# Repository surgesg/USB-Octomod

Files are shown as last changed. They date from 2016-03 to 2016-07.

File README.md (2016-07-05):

# USB-Octomod

The USB-Octomod is a USB device which allows generation of computer-controlled analog synthesizer control voltages
in the range of approximately +/- 5V.
Using a small open-source and cross-platform host application, the user is able to control the 8 output channels
of the Octomod through a simple OSC/MIDI interface. 
The OSC interface allows composers, musicians, etc. to control the Octomod from their software environment of choice.

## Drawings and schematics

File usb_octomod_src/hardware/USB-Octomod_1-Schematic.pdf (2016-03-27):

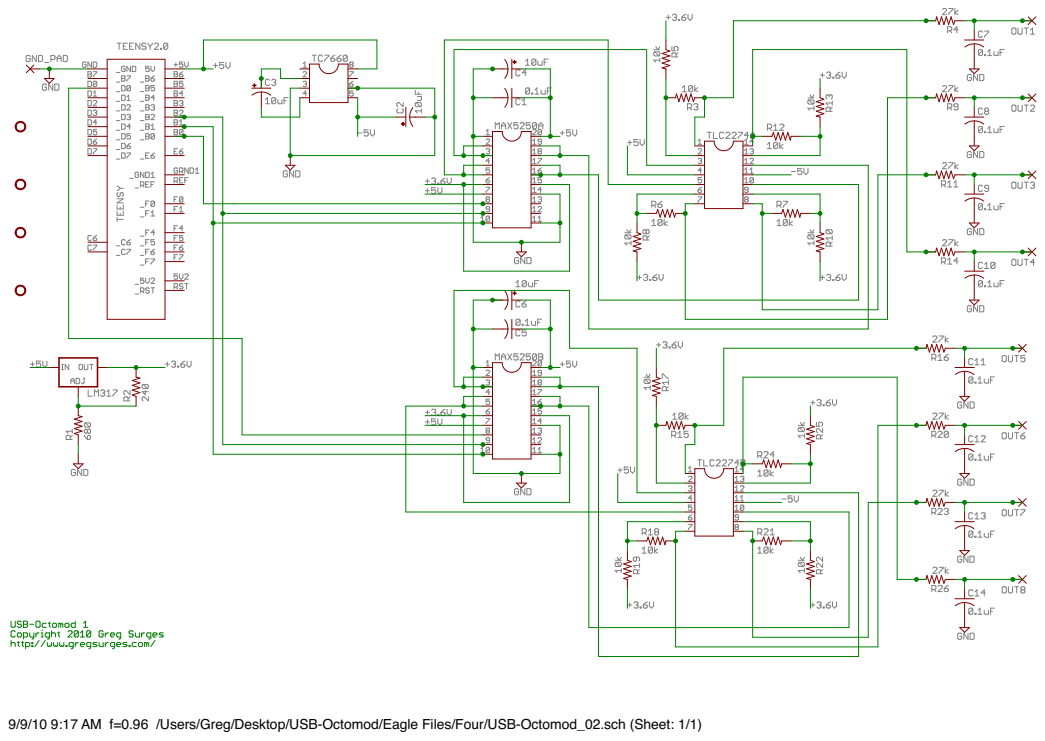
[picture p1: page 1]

9/9/10 9:17 AM f=0.96 /Users/Greg/Desktop/USB-Octomod/Eagle Files/Four/USB-Octomod_02.sch (Sheet: 1/1)

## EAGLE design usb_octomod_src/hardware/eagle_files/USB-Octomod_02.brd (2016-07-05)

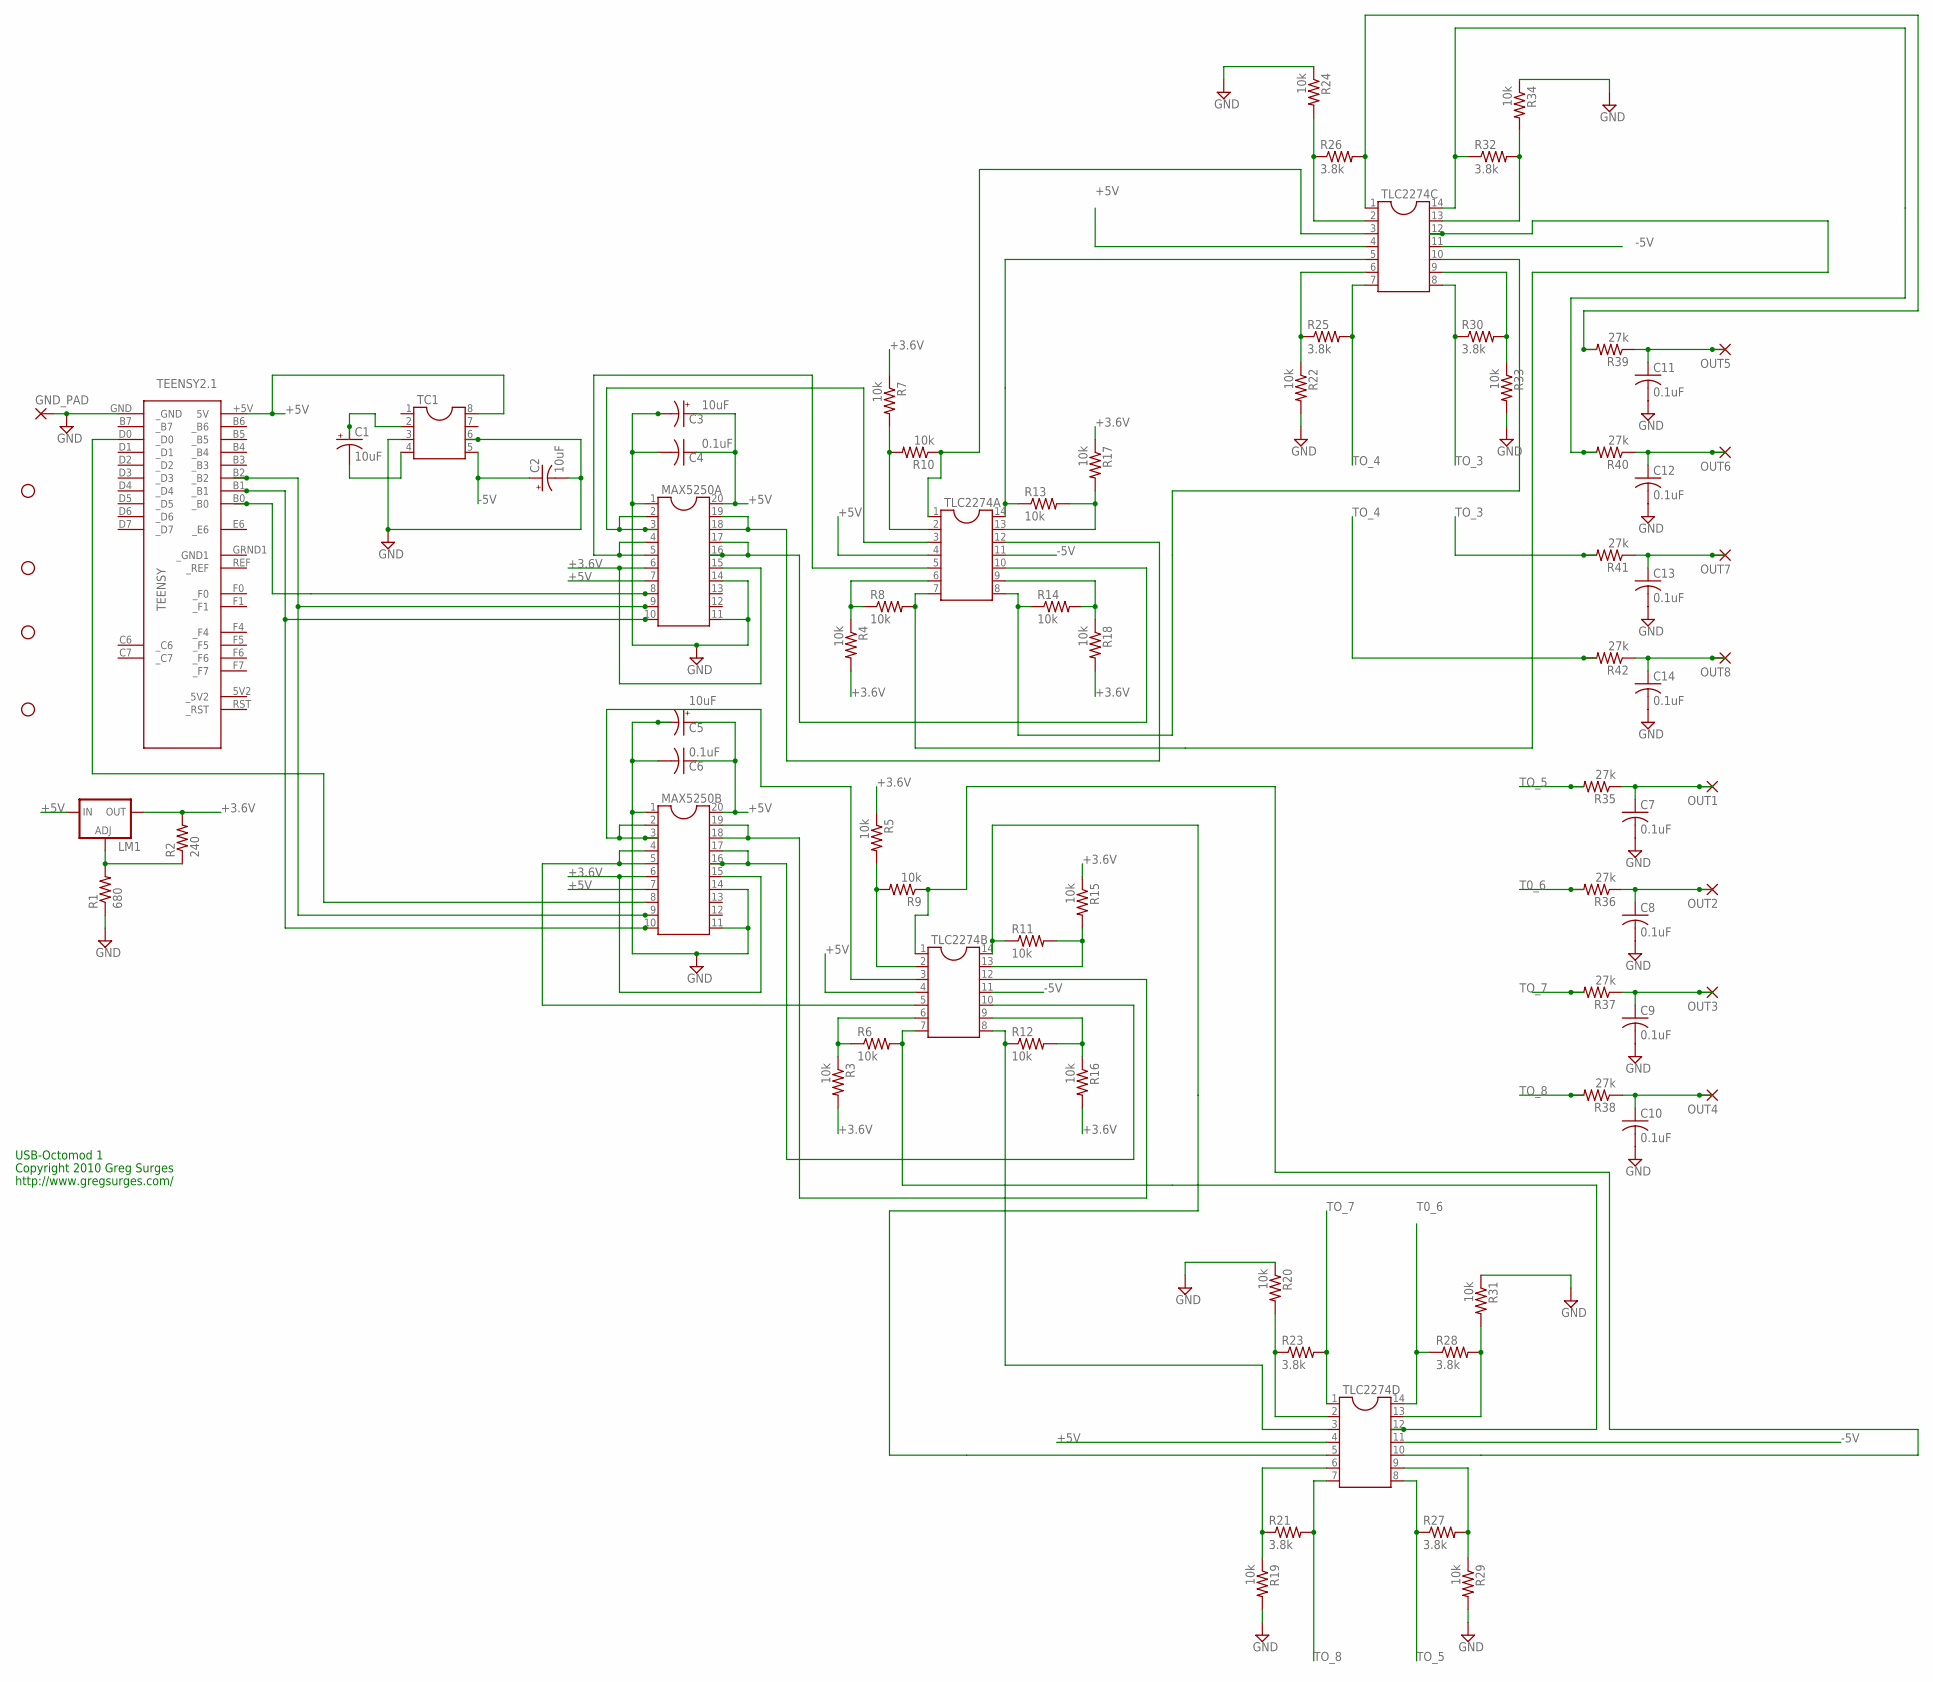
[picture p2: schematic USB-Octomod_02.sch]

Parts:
C1, C2, C3, C5: 10uF; E2,5-6
C4, C6, C7, C8, C9, C10, C11, C12, C13, C14: 0.1uF; C025-040X050
GND_PAD: 2,15/1,0
JP1, JP2, JP3, JP4: STAND-OFF
LM1: LM317TL; 317TL
MAX5250A, MAX5250B: DIL20
OUT1, OUT2, OUT3, OUT4, OUT5, OUT6, OUT7, OUT8: 2,15/1,0
R1: 680; 0207/10
R2: 240; 0207/10
R3, R4, R5, R6, R7, R8, R9, R10, R11, R12, R13, R14, R15, R16, R17, R18, R19, R20, R22, R24, R29, R31, R33, R34: 10k; 0207/10
R21, R23, R25, R26, R27, R28, R30, R32: 3.8k; 0207/10
R35, R36, R37, R38, R39, R40, R41, R42: 27k; 0207/10
TC1: DIL8; DIL08
TEENSY2.1: TEENSY
TLC2274A, TLC2274B, TLC2274C, TLC2274D: DIL14

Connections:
+3.6V: LM1.2 (OUT), MAX5250A.6, MAX5250A.15, MAX5250B.6, MAX5250B.15, R2.2, R3.2, R4.2, R5.1, R7.1, R15.1, R16.2, R17.1, R18.2
+5V: C3.+, C4.1, C5.+, C6.1, LM1.3 (IN), MAX5250A.7, MAX5250A.20, MAX5250B.7, MAX5250B.20, TC1.8, TEENSY2.1.+5V (5V), TLC2274A.4, TLC2274B.4, TLC2274C.4, TLC2274D.4
-5V: C2.+, TC1.5, TLC2274A.11, TLC2274B.11, TLC2274C.11, TLC2274D.11
GND: C2.-, C3.-, C4.2, C5.-, C6.2, C7.2, C8.2, C9.2, C10.2, C11.2, C12.2, C13.2, C14.2, GND_PAD.1, MAX5250A.1, MAX5250A.11, MAX5250A.14, MAX5250B.1, MAX5250B.11, MAX5250B.14, R1.1, R19.2, R20.1, R22.2, R24.1, R29.2, R31.1, R33.2, R34.1, TC1.3, TC1.6, TEENSY2.1.GND (_GND)
unnamed: MAX5250A.8, TEENSY2.1.B0 (_B0)
unnamed: MAX5250A.10, MAX5250B.10, TEENSY2.1.B1 (_B1)
unnamed: MAX5250A.9, MAX5250B.9, TEENSY2.1.B2 (_B2)
unnamed: C1.+, TC1.2
unnamed: R10.1, TLC2274A.1, TLC2274C.3
unnamed: LM1.1 (ADJ), R1.2, R2.1
unnamed: C1.-, TC1.4
unnamed: R7.2, R10.2, TLC2274A.2
unnamed: C11.1, OUT5.1, R39.1
unnamed: R4.1, R8.1, TLC2274A.6
unnamed: R13.2, R17.2, TLC2274A.13
unnamed: C12.1, OUT6.1, R40.1
unnamed: C13.1, OUT7.1, R41.1
unnamed: C14.1, OUT8.1, R42.1
unnamed: R5.2, R9.2, TLC2274B.2
unnamed: C7.1, OUT1.1, R35.1
unnamed: R3.1, R6.1, TLC2274B.6
unnamed: C8.1, OUT2.1, R36.1
unnamed: C9.1, OUT3.1, R37.1
unnamed: R11.2, R15.2, TLC2274B.13
unnamed: C10.1, OUT4.1, R38.1
unnamed: R14.2, R18.1, TLC2274A.9
unnamed: R12.2, R16.1, TLC2274B.9
unnamed: MAX5250B.8, TEENSY2.1.D0 (_D0)
unnamed: R24.2, R26.1, TLC2274C.2
unnamed: R26.2, R39.2, TLC2274C.1
unnamed: R32.2, R34.2, TLC2274C.13
unnamed: R32.1, R40.2, TLC2274C.14
unnamed: R22.1, R25.1, TLC2274C.6
unnamed: R30.2, R33.1, TLC2274C.9
unnamed: R20.2, R23.1, TLC2274D.2
unnamed: R28.2, R31.2, TLC2274D.13
unnamed: R19.1, R21.1, TLC2274D.6
unnamed: R27.2, R29.1, TLC2274D.9
OUT2: R8.2, TLC2274A.7, TLC2274C.12
OUT3: R14.1, TLC2274A.8, TLC2274C.10
OUT4: R13.1, TLC2274A.14, TLC2274C.5
OUT6: R11.1, TLC2274B.14, TLC2274D.5
OUT8: R9.1, TLC2274B.1, TLC2274D.10
OUTA1: MAX5250A.2, MAX5250A.3, TLC2274A.3
OUTA2: MAX5250A.4, MAX5250A.5, TLC2274A.5
OUTA3: MAX5250A.18, MAX5250A.19, TLC2274A.12
OUTA4: MAX5250A.16, MAX5250A.17, TLC2274A.10
OUTB1: MAX5250B.2, MAX5250B.3, TLC2274B.3
OUTB2: MAX5250B.4, MAX5250B.5, TLC2274B.5
OUTB3: MAX5250B.18, MAX5250B.19, TLC2274B.12
OUTB4: MAX5250B.16, MAX5250B.17, TLC2274B.10
T0_6: R28.1, R36.2, TLC2274D.14
TO_3: R30.1, R41.2, TLC2274C.8
TO_4: R25.2, R42.2, TLC2274C.7
TO_5: R27.1, R35.2, TLC2274D.8
TO_7: R23.2, R37.2, TLC2274D.1
TO_8: R21.2, R38.2, TLC2274D.7
TT3: R12.1, TLC2274B.8, TLC2274D.3
TTT: R6.2, TLC2274B.7, TLC2274D.12

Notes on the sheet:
USB-Octomod 1
Copyright 2010 Greg Surges
http://www.gregsurges.com/

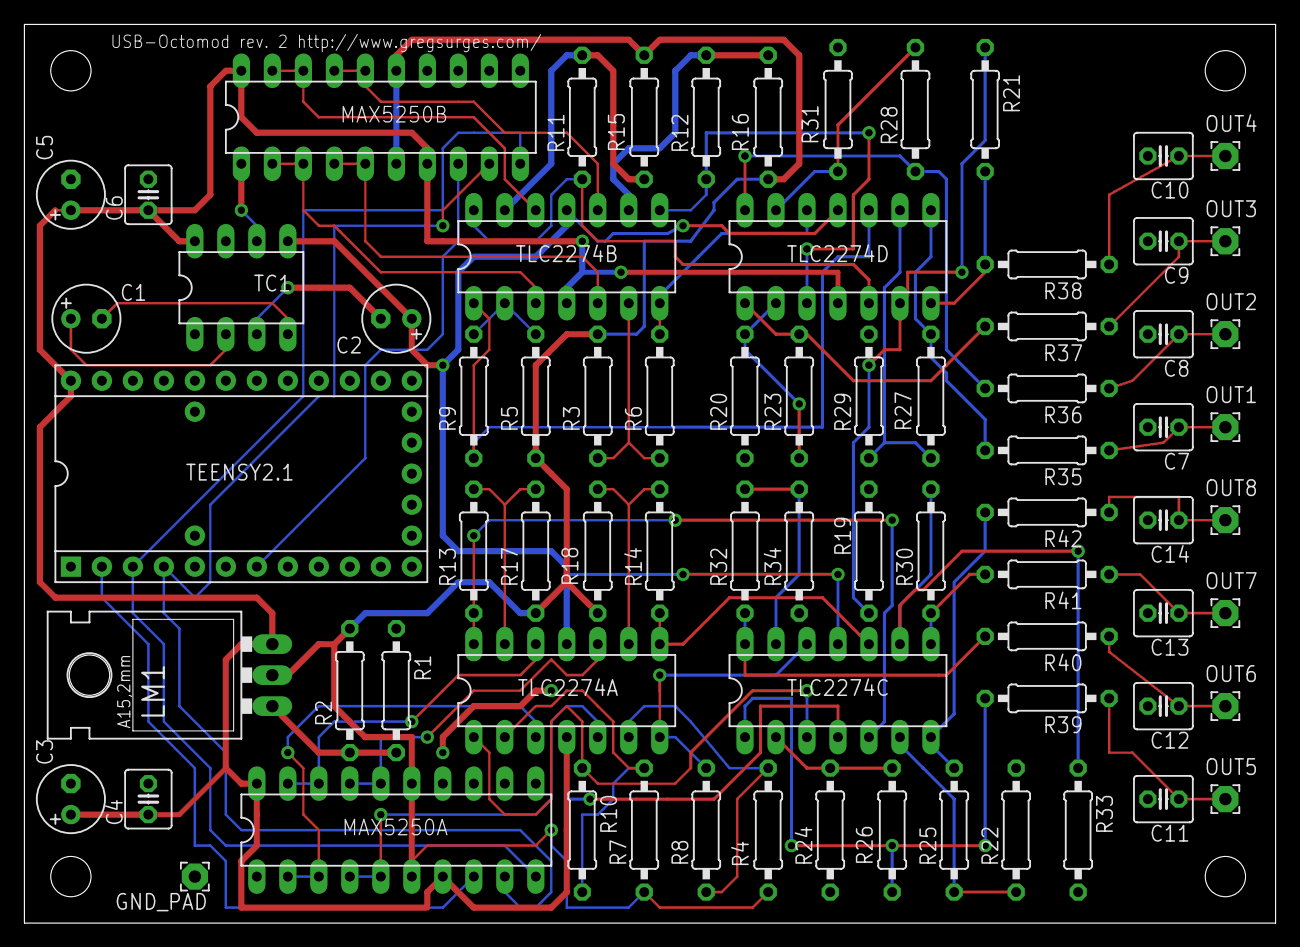
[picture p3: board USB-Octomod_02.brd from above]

Board: 2 copper layers, 102.5 x 73.7 mm, 78 parts (0 on the bottom side), 59 nets.

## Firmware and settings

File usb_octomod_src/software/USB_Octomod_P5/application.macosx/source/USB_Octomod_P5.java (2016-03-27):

import processing.core.*; 
import processing.xml.*; 

import themidibus.*; 
import controlP5.*; 
import oscP5.*; 
import netP5.*; 
import processing.serial.*; 

import java.applet.*; 
import java.awt.Dimension; 
import java.awt.Frame; 
import java.awt.event.MouseEvent; 
import java.awt.event.KeyEvent; 
import java.awt.event.FocusEvent; 
import java.awt.Image; 
import java.io.*; 
import java.net.*; 
import java.text.*; 
import java.util.*; 
import java.util.zip.*; 
import java.util.regex.*; 

public class USB_Octomod_P5 extends PApplet {

/*   
 USB_Octomod_P5.pde
 USB-Octomod OSC Host Program
 Version 2 - updated 11.13.2010
 Copyright 2010, Greg Surges
 surgesg@gmail.com
 http://www.gregsurges.com/
 
 Copyright (c) 2010, Greg Surges
 All rights reserved.
 
 Redistribution and use in source and binary forms, with or without modification, are permitted provided that the following conditions are met:
 
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
 THIS SOFTWARE IS PROVIDED BY THE COPYRIGHT HOLDERS AND CONTRIBUTORS "AS IS" AND ANY EXPRESS OR IMPLIED WARRANTIES, INCLUDING, 
 BUT NOT LIMITED TO, THE IMPLIED WARRANTIES OF MERCHANTABILITY AND FITNESS FOR A PARTICULAR PURPOSE ARE DISCLAIMED. IN NO EVENT 
 SHALL THE COPYRIGHT HOLDER OR CONTRIBUTORS BE LIABLE FOR ANY DIRECT, INDIRECT, INCIDENTAL, SPECIAL, EXEMPLARY, OR CONSEQUENTIAL DAMAGES
 (INCLUDING, BUT NOT LIMITED TO, PROCUREMENT OF SUBSTITUTE GOODS OR SERVICES; LOSS OF USE, DATA, OR PROFITS; OR BUSINESS INTERRUPTION) HOWEVER 
 CAUSED AND ON ANY THEORY OF LIABILITY, WHETHER IN CONTRACT, STRICT LIABILITY, OR TORT (INCLUDING NEGLIGENCE OR OTHERWISE) ARISING IN ANY WAY 
 OUT OF THE USE OF THIS SOFTWARE, EVEN IF ADVISED OF THE POSSIBILITY OF SUCH DAMAGE.
 */







ControlP5 controlP5;
Serial teensy;
OscP5 oscP5;

ListBox l, midiList;
Numberbox portBox;
MidiBus midi;

int channel; // first osc argument, corresponds to DAC output channel (0 - 7) 
int inputData; // second osc argument, 10-bit number to output
int updateBits = 3; // dac update behavior register, update immediately when data received
int dacChip; // used to select one of the two chips
int spiWord; // the assembled 16-bit word is stored here before output over serial
String binaryString; 
ArrayList <Byte> outputData = new ArrayList();
byte outputBytes[];
int dataIndex = 0;
int data[];
double previousUpdate = 0;
double currentTime;
String portName;
boolean serialConnected = false;
int newPort = 9999;
boolean portNeedsUpdate = false;

int channelData[]; // store current output value for each channel
boolean newData[];
Slider sliders[];
Slider sliderOne, sliderTwo, sliderThree, sliderFour, sliderFive, sliderSix, sliderSeven, sliderEight;

PFont font;

public void setup() {
  size(710, 175);
  frameRate(16);
  midi = new MidiBus(this, 0, 0);
  controlP5 = new ControlP5(this);

  l = controlP5.addListBox("serialPorts", 550, 65, 140, 140);
  l.setItemHeight(15);
  l.setBarHeight(15);

  l.captionLabel().toUpperCase(true);
  l.captionLabel().set("serial ports");
  l.captionLabel().style().marginTop = 3;
  l.valueLabel().style().marginTop = 3; // the +/- sign
  for(int i=0; i < Serial.list().length; i++) {
    l.addItem(Serial.list()[i],i);
  }
  
  midiList = controlP5.addListBox("midiPorts", 15, 33, 140, 140);
  midiList.setItemHeight(15);
  midiList.setBarHeight(15);
  midiList.captionLabel().toUpperCase(true);
  midiList.captionLabel().set("MIDI inputs");
  midiList.captionLabel().style().marginTop = 3;
  midiList.valueLabel().style().marginTop = 3;
  for(int i=0; i < midi.availableInputs().length; i++) {
    midiList.addItem(midi.availableInputs()[i],i);
  }  
  //l.setColorLabel(color(100, 200, 50));
  //l.close();

  portBox = controlP5.addNumberbox("port", 550, 15, 140, 15);
  portBox.setValue(9999);
  portBox.setId(1);
  portBox.setColorLabel(color(0, 0, 0));
  portBox.setDecimalPrecision(0);

  oscP5 = new OscP5(this, 9999); // start oscp5 listen on port 9999
  outputData = new ArrayList();
  outputBytes = new byte[1];
  channelData = new int[8];
  newData = new boolean[8];
  data = new int[8];
  font = loadFont("Monaco-9.vlw");
  textFont(font, 9);
  fill(100, 200, 50);
  stroke(100, 200, 50);
  sliders = new Slider[8];
  sliders[0] = new Slider(270, 40, 275);
  sliders[1] = new Slider(270, 55, 275);
  sliders[2] = new Slider(270, 70, 275);
  sliders[3] = new Slider(270, 85, 275);    
  sliders[4] = new Slider(270, 100, 275);
  sliders[5] = new Slider(270, 115, 275);
  sliders[6] = new Slider(270, 130, 275);
  sliders[7] = new Slider(270, 145, 275);
}

public void draw() {
  if(!mousePressed && portNeedsUpdate) {
    oscP5.dispose();      
    oscP5 = new OscP5(this, newPort); // start oscp5 listen on port 9999
    portNeedsUpdate = false;
  }
  background(250, 250, 255); 
  fill(0, 0, 0, 100);
  rect(10, 10, width - 20, height - 20);
  fill(250, 255, 255, 200);
  rect(160, 15, 385, 144);
  fill(0, 0, 0);
  stroke(0, 0, 0);
  text("SERIAL: "+ portName +" OSC: LISTENING ON PORT: "+ newPort +".", 165, 30);
  text("/CHANNEL 1: " + channelData[0], 165, 45);
  text("/CHANNEL 2: " + channelData[1], 165, 60);
  text("/CHANNEL 3: " + channelData[2], 165, 75);
  text("/CHANNEL 4: " + channelData[3], 165, 90);
  text("/CHANNEL 5: " + channelData[4], 165, 105);
  text("/CHANNEL 6: " + channelData[5], 165, 120);
  text("/CHANNEL 7: " + channelData[6], 165, 135);
  text("/CHANNEL 8: " + channelData[7], 165, 150); 
  for(int i = 0; i < 8; i++) {
    sliders[i].update(channelData[i]);
  }
}


// need to update to select midi in port. MidiBus.list() will list them, this should be in a listbox
public void controllerChange(int channel, int number, int value){
  if(number >= 20 || number <= 27){
    channelData[number - 20] = (int)map(value, 0, 127, 0, 1023);
    writeValue(number - 20, PApplet.parseInt(map(value, 0, 127, 0, 1023)));  
  }
}

public void oscEvent(OscMessage theOscMessage) {
  println(theOscMessage);
  if(serialConnected) { 
    if(theOscMessage.checkAddrPattern("/dac")==true) {
      for(int i = 0; i < 8; i++) {
        data[i] = (int)theOscMessage.get(i).intValue();
        if(data[i] != channelData[i]) {
          channelData[i] = data[i];
          newData[i] = true;
        } 
        else {
          newData[i] = false;
        }
      }
      for(int i = 0; i < 8; i++) {  
          println(data[i] + " " + channelData[i] + " " + newData[i]);
         if(newData[i] == true) {
           println("new data sent over serial");
          writeValue(i, channelData[i]); // should probably only call this function if the value has changed (save a lot of time)
          }
      }
    }
  }
}

public void writeValue(int _channel, int _data) {
  if(_channel > 3) { // assign one of two dac chips to respond
    dacChip = 1;
  } 
  else {
    dacChip = 0;
  }

  /* bit shifting and masking to assemble proper list of bits */
  _channel = _channel << 14;
  updateBits = 3 << 12;
  _channel = _channel | updateBits; // OR to combine
  _data = _data << 2;
  spiWord = _channel | _data;
  binaryString = binary(spiWord, 16);

  outputData.add(PApplet.parseByte(dacChip));
  outputData.add(PApplet.parseByte(unbinary(binaryString.substring(0, 8))));
  outputData.add(PApplet.parseByte(unbinary(binaryString.substring(8, 16))));
  currentTime = millis();
  if(outputData.size() >= 24 || currentTime - previousUpdate >= 10) {
    outputBytes = new byte[outputData.size()];
    for(int i = 0; i < outputData.size(); i++) {
      outputBytes[i] = outputData.get(i);
    }
    teensy.write(outputBytes);
   // println(outputBytes);
    dataIndex = 0;
    outputData = new ArrayList();
    previousUpdate = currentTime;
    }
}

class Slider {
  int x, y, value, center;
  int w = 265;
  int h = 12;

  Slider() {
  }

  Slider(int _x, int _y, int _value) {
    x = _x;
    y = _y;
    value = _value;
  }

  public int getX() {
    return x;
  }

  public int getY() {
    return y;
  }

  public void setX(int _x) {
    x = _x;
  }

  public void setY(int _y) {
    y = _y;
  }

  public int getValue() {
    return value;
  }

  public void setValue(int _value) {
    value = _value;
  }
  public void update(int _value) {
    setValue(_value);
    drawLine();
    drawPuck();
  }

  public void drawLine() {
    line(x, y, x + w, y);
  }
  public void drawPuck() {
    center = (int)map(value, 0, 1023, 0, w);
    ellipse(x + center, y, 6, 6);
  }
}

public void controlEvent(ControlEvent theEvent) {
  if(theEvent.isGroup()) {
    if(theEvent.group().name() == "serialPorts") { 
      teensy = new Serial(this, Serial.list()[(int)theEvent.group().value()], 115200); // open serial port, 115200 rate
      teensy.buffer(1); // seems like this should make transmission more robust, not probably necessary
      portName = ""+ Serial.list()[(int)theEvent.group().value()];
      serialConnected = true;
      return;
    }
    if(theEvent.group().name() == "midiPorts"){
      midi = new MidiBus(this, midi.availableInputs()[(int)theEvent.group().value()], 1);
      println("MIDI port: " + midi.availableInputs()[(int)theEvent.group().value()] + " connected.");   
      midi.clearOutputs();
      return;
    }
  }
  if(theEvent.controller().id() == 1) {
    newPort = (int)theEvent.controller().value();
    portNeedsUpdate = true;
  }
}

  static public void main(String args[]) {
    PApplet.main(new String[] { "--bgcolor=#FFFFFF", "USB_Octomod_P5" });
  }
}

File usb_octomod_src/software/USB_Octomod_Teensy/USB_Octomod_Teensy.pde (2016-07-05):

// added to svn
#include "spi.h"
#include <avr/io.h>
/*  
 SPI_Interface_6232010 
 created 6.23.2010 by Greg Surges
 to allow for interfacing between usb/Serial data and 10-bit DAC (MAX5250 currently)
 using Teensy 2.0
 
 copyright 2010-2016 greg surges
 surgesg@gmail.com
 
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
    You should have received a copy of the GNU General Public License
    along with this program.  If not, see <http://www.gnu.org/licenses/>.
 */

#define SELECT_DAC_ONE digitalWrite(PORTB0, LOW);
#define DESELECT_DAC_ONE digitalWrite(PORTB0, HIGH);
#define SELECT_DAC_TWO digitalWrite(PIN_D0, LOW);
#define DESELECT_DAC_TWO digitalWrite(PIN_D0, HIGH);

#define CPU_PRESCALE(n) (CLKPR = 0x80, CLKPR = (n))
#define CPU_16MHz       0x00
#define CPU_8MHz        0x01
#define CPU_4MHz        0x02
#define CPU_2MHz        0x03
#define CPU_1MHz        0x04
#define CPU_500kHz      0x05
#define CPU_250kHz      0x06
#define CPU_125kHz      0x07
#define CPU_62kHz       0x08


byte clr;
byte byteOne, byteTwo;
byte firstByte, secondByte, thirdByte;
boolean data;

void setup(){
  CPU_PRESCALE(CPU_4MHz);
  pinMode(PORTB0, OUTPUT);
  pinMode(PIN_D0, OUTPUT);
  Serial.begin(9600);
  DESELECT_DAC_ONE;
  DESELECT_DAC_TWO;
  setup_spi(SPI_MODE_0, SPI_MSB, SPI_NO_INTERRUPT, SPI_MSTR_CLK2);
}

void loop(){
  pollAndWrite();
}

void pollAndWrite(){
 data = false;
 while(!data){
  if(Serial.available()) { // look into the receive buffering - not receiving from Max properly
    firstByte = Serial.read();
    delayMicroseconds(100);
    if(firstByte == B00000000) {
      secondByte = Serial.read();
      delayMicroseconds(100);
      thirdByte = Serial.read();
      SELECT_DAC_ONE;
      send_spi(secondByte);
      send_spi(thirdByte);
      delayMicroseconds(10);
      DESELECT_DAC_ONE;
      data = true;
    } 
      if(firstByte == B00000001){
        secondByte = Serial.read();
        delayMicroseconds(100);
        thirdByte = Serial.read();     
        SELECT_DAC_TWO;
        send_spi(secondByte);
        send_spi(thirdByte);
        delayMicroseconds(10);
        DESELECT_DAC_TWO;
        data = true;
    }
  }
 }
}

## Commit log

2016-07-05 added .brd file
    [USB-Octomod_02.brd]
2016-07-05 added .sch file
    [USB-Octomod_02.sch]
2016-07-05 added schematic pdf file

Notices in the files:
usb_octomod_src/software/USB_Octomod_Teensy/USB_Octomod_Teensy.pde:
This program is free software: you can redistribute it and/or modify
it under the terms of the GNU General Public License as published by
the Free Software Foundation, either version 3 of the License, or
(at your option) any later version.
